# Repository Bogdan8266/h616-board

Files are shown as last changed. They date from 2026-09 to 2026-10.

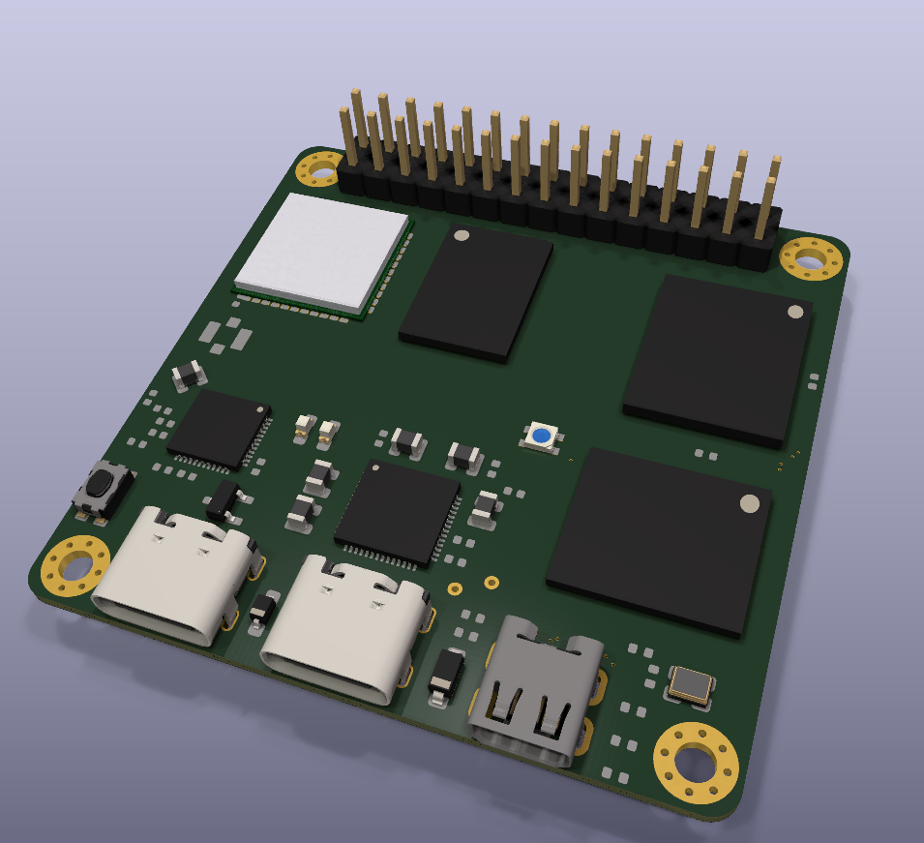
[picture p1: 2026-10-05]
pics/3d-render.png

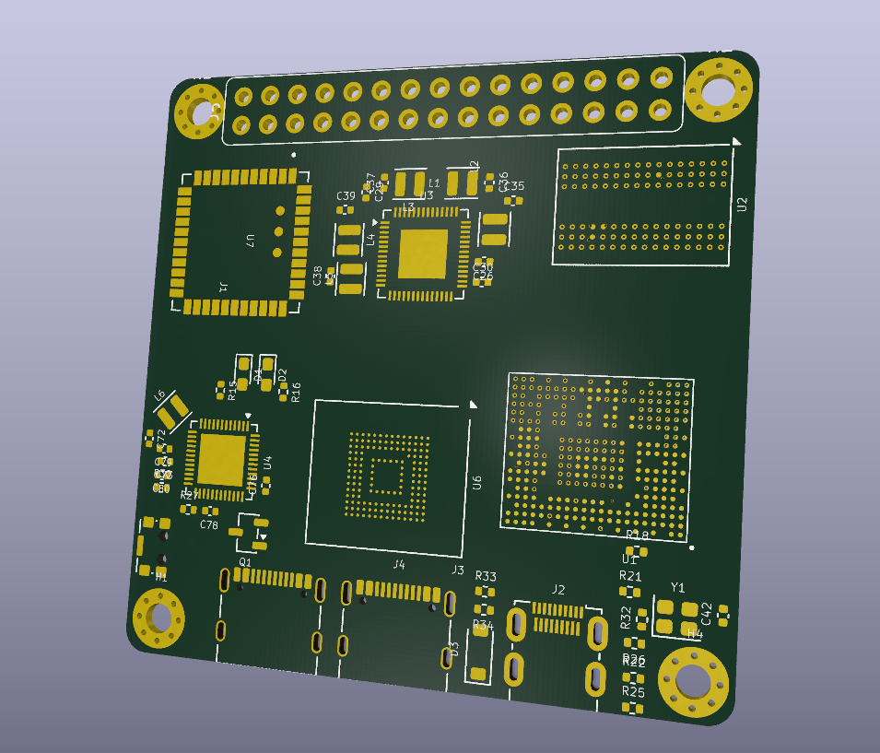
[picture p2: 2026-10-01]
pics/Pasted image (2).png

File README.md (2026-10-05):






# Nebula board

A brief description of my Allwinner H616 board.
A minimalist board measuring 50 mm by 35 mm (subject to change)
# JLCPCB & LCSC
The main challenge with this 8-layer board is using an available stackup from JLCPCB as of August 29, 2026, I recommend [**JLC08101H-1080 (/Finished thickness 1.02 mm ±10%**.](https://jlcpcb.com/pcb-impedance-calculator)
  
Another challenge is that the via holes are 0.3 mm in size (0.35/0.45 mm). 
With these parameters, [JLCPCB](https://cart.jlcpcb.com/) allows you to manufacture the board for $2 USD. Any change will make the price astronomical.
For example, it is not recommended to change the **minimum via hole size/diameter.**
For via covering, I used “via in pad,” so the manufacturer does not allow the via to remain unfilled with epoxy. 
Dimensions up to 50 mm by 40 mm 
If you have the budget, I recommend simply assembling a board based on the original  [Kononenko-K](https://github.com/Kononenko-K/Allwinner_H616_Devboard) design or redesigning my board, because there’s no point in doing this if you don’t want to order a PCB at a promotional price like I did—you’ll waste a lot of energy and may sacrifice stability.

PCB assembly, LCSC isn’t supported in Ukraine, of course, you can use a mail forwarding service, but I’m interested in soldering the board myself and buying parts cheaper on marketplaces—and that same **V3S** costs me practically nothing on the market. If you’re making a board for PCB assembly, it’s worth making it single-sided to save money, but the economical PCBA mode isn’t supported for BGA soldering, and it costs $25, so there’s no point in doing that.
# RAM
My board has only one DDR3 chip, up to 1 GB, but if you’re looking for performance, two chips provide twice as much memory and twice the speed.

It's important to note that the H616 supports 16- or 32-bit RAM; according to **JEDEC**, a single DDR3 chip has a maximum of ***16 bits, so you'll need 16-bit RAM specifically.***

### SK Hynix  
* H5TQ1G63BFR (1 Gb / 128 MB)  
* H5TQ2G63BFR / H5TQ2G63DFR (2 Gb / 256 MB)  
* H5TQ4G63AFR / H5TQ4G63CFR / H5TQ4G63MFR (4 Gb / 512 MB)  
* H5TC8G63AMR / H5TC8G63CMR (8 Gb / 1 GB — low-voltage DDR3L)  
### Samsung  
* K4B1G1646G / K4B1G1646I (1 Gb / 128 MB)  
* K4B2G1646E / K4B2G1646F (2 Gb / 256 MB)  
* K4B4G1646D / K4B4G1646E (4 Gb / 512 MB)  
* K4B8G1646D / K4B8G1646B (8 Gb / 1 GB)  
### Micron  
* MT41J64M16 (1 Gb / 128 MB)  
* MT41J128M16 / MT41K128M16 (2 Gb / 256 MB)  
* MT41J256M16 / MT41K256M16 (4 Gb / 512 MB)  
* MT41J512M16 / MT41K512M16 (8 Gb / 1 GB)  
### Nanya  
* NT5CB64M16 (1 Gb / 128 MB)  
* NT5CB128M16 / NT5CC128M16 (2 Gb / 256 MB)  
* NT5CB256M16 / NT5CC256M16 (4 Gb / 512 MB)  
* NT5CC512M16 (8 Gb / 1 GB)**

## EDA
I’m screwing around with the layout because the DDR was really hard to route, and I lost all motivation working in KiCad—the wise will skip KiCad and download Altium, so think carefully about which software to use. 
## Connection
For Wi-Fi/Bluetooth, I’d choose a board based on the **RTL8821CS** for better speed and so on, because Wi-Fi connects via GPIO (i.e., **SDIO**) and Bluetooth via **UART**. But since there are 3 free USB channels, I’ll connect an **RTL8821CU** board to them for a simple USB connection. Feel free to use any other wireless module that suits your needs; **5 (5.8) GHz** support is important to me, which is why I chose the RTL8821CU, but I recommend taking a closer look at Broadcom options.

## Power

Since I’m planning for standalone operation, and the PMIC **AXP305** wasn’t designed for that—only for monotonous operation from a power supply in TV set-top boxes—it doesn’t support a battery, and there’s certainly no datasheet for it. According to the developer, we’re supposed to use only the reference design together with the **H616**—so be it. 

The **SW6206** is a versatile “all-in-one” microcontroller for power banks that supports fast charging up to 22.5 W. It supports simultaneous operation of up to 5 ports and is compatible with nearly all modern power delivery protocols, including ***PD 3.0, QC 4+, and PPS.***
Therefore, if you plan to run the device on battery power, one USB port is dedicated exclusively to charging; it is not used for data transmission with the board, since smart charging protocols like QC and PD require a data line in the cable.
 # Flux & Paste

For *double-sided soldering*, I recommend purchasing solder pastes: low-temperature (bismuth-based, **~138°C)** and medium-/high-temperature (lead-based, **~183°C**, or lead-free, **~217°C**).

**MECHANIC V5B45** Sn42/Bi58 Solder Paste: Composition and Temperature: Tin-bismuth alloy (Sn42/Bi58) with a precise melting point of **138°C**. For the top side of **BGAs**.

**BS458** Mechanic Solder Paste: Features: A low-melting-point, lead-free, RoHS-compliant formulation supplied in convenient jars. For the back side, resistors, and capacitors.

# Documentation & Soldering      WARNING!!!
[***This***](https://csbible.com/wp-content/uploads/2018/03/CSB_Pew_Bible_2nd_Printing.pdf)
<p align="right"> 
  Views
</p>

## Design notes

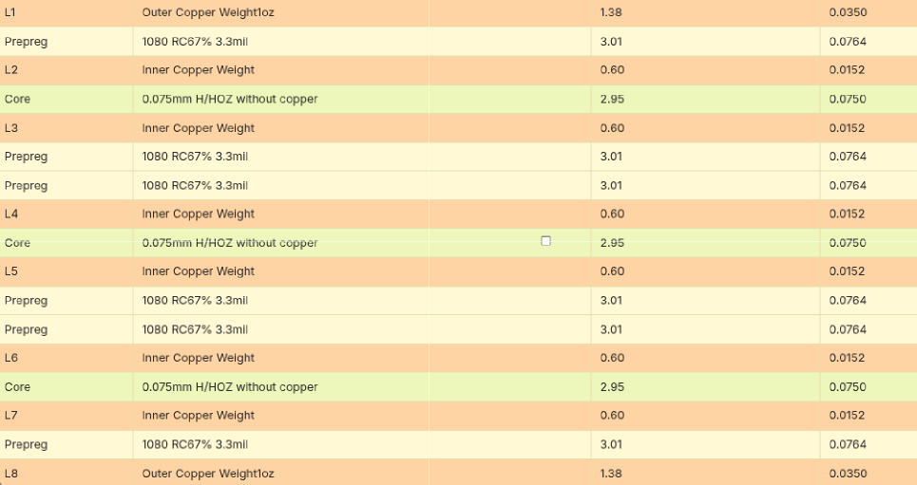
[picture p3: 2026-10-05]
pics/stack2.png

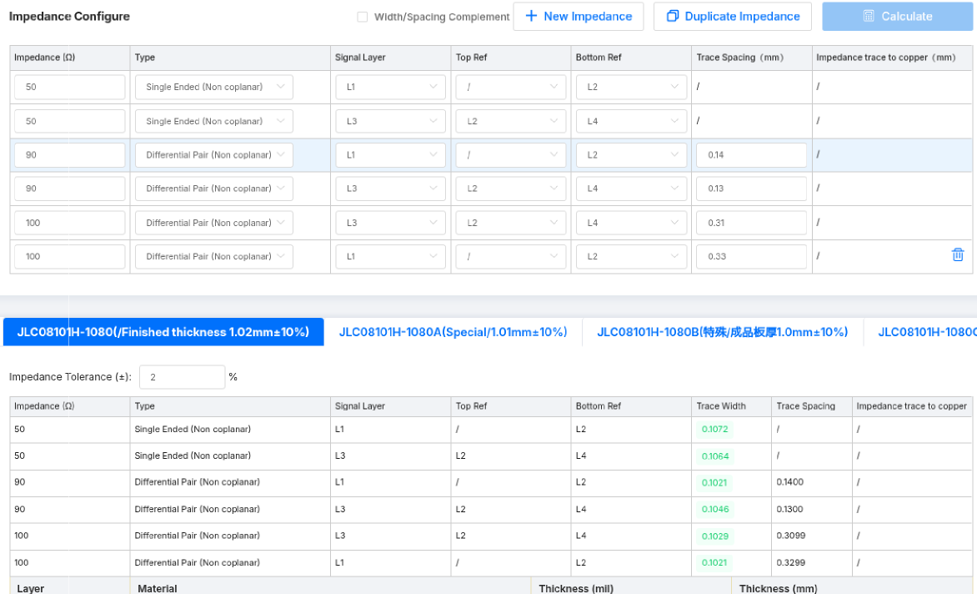
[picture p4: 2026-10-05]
pics/stack.png

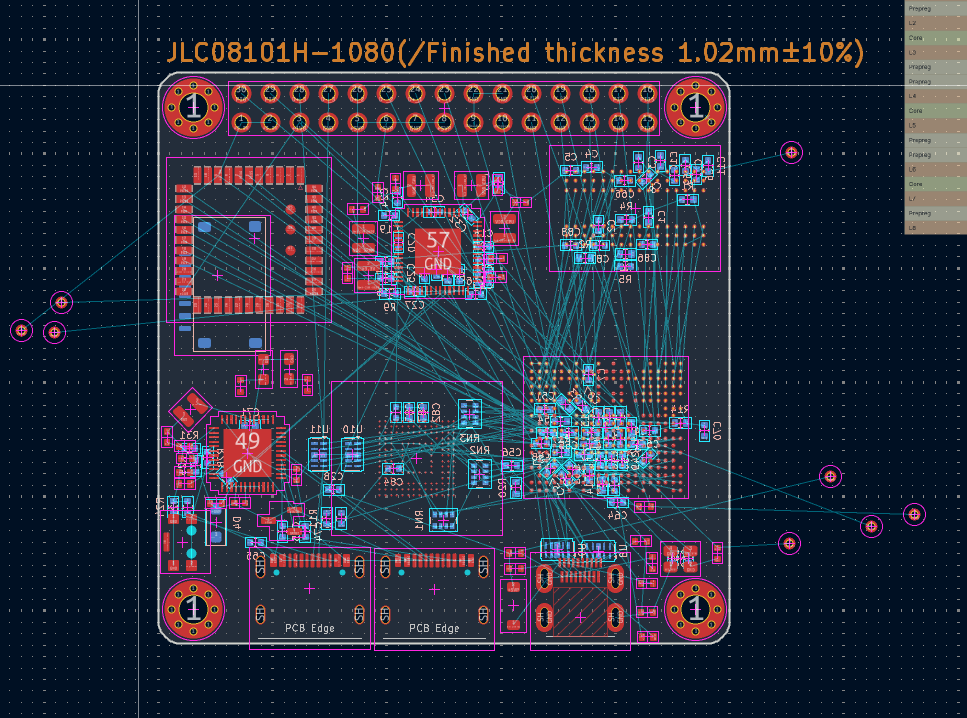
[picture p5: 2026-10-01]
pics/Pasted image.png

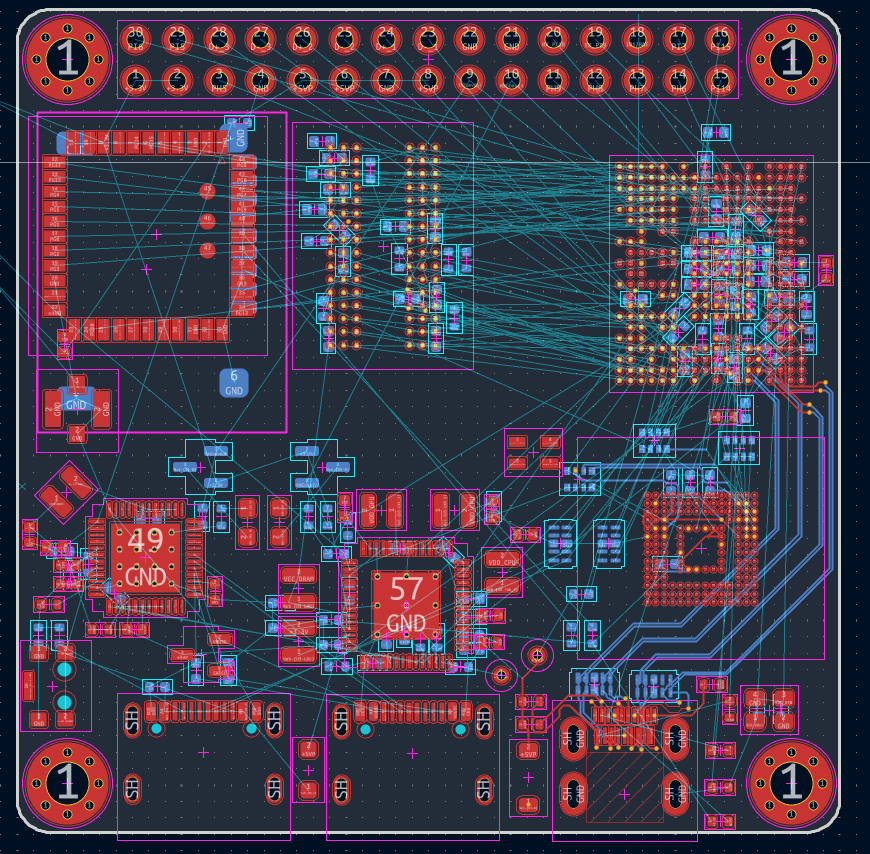
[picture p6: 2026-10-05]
pics/pcb.png

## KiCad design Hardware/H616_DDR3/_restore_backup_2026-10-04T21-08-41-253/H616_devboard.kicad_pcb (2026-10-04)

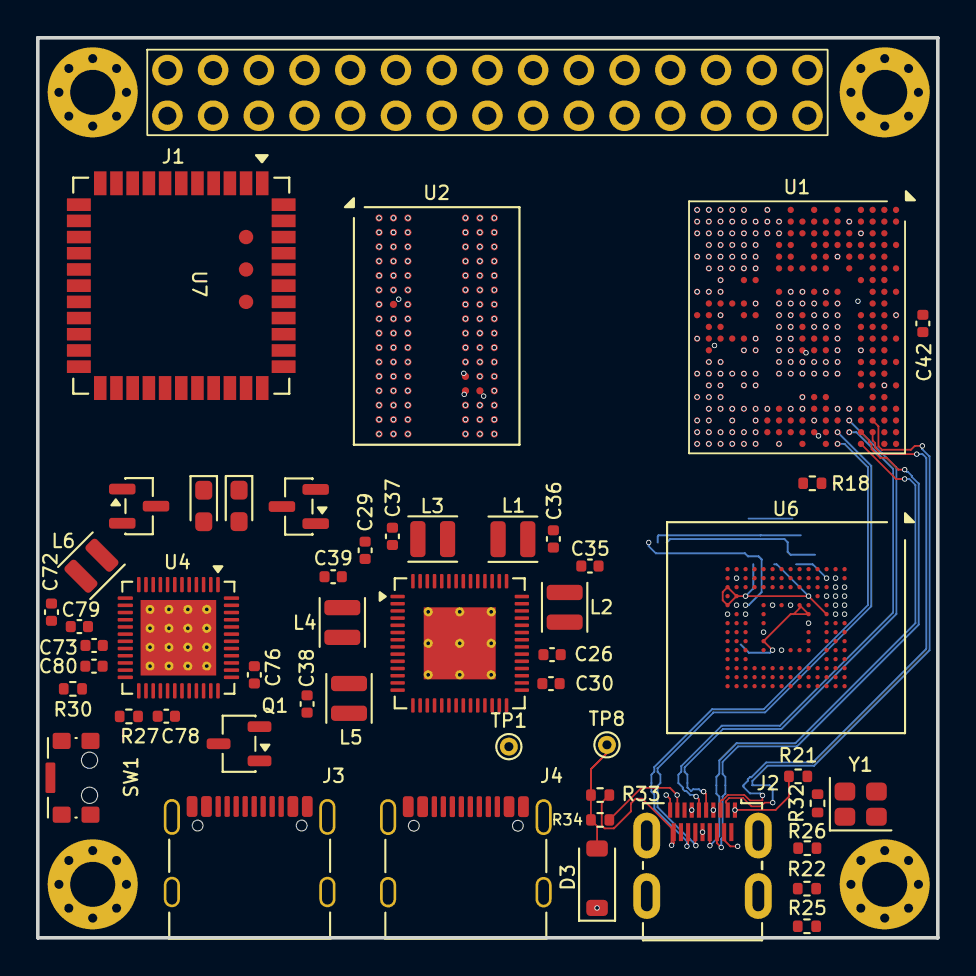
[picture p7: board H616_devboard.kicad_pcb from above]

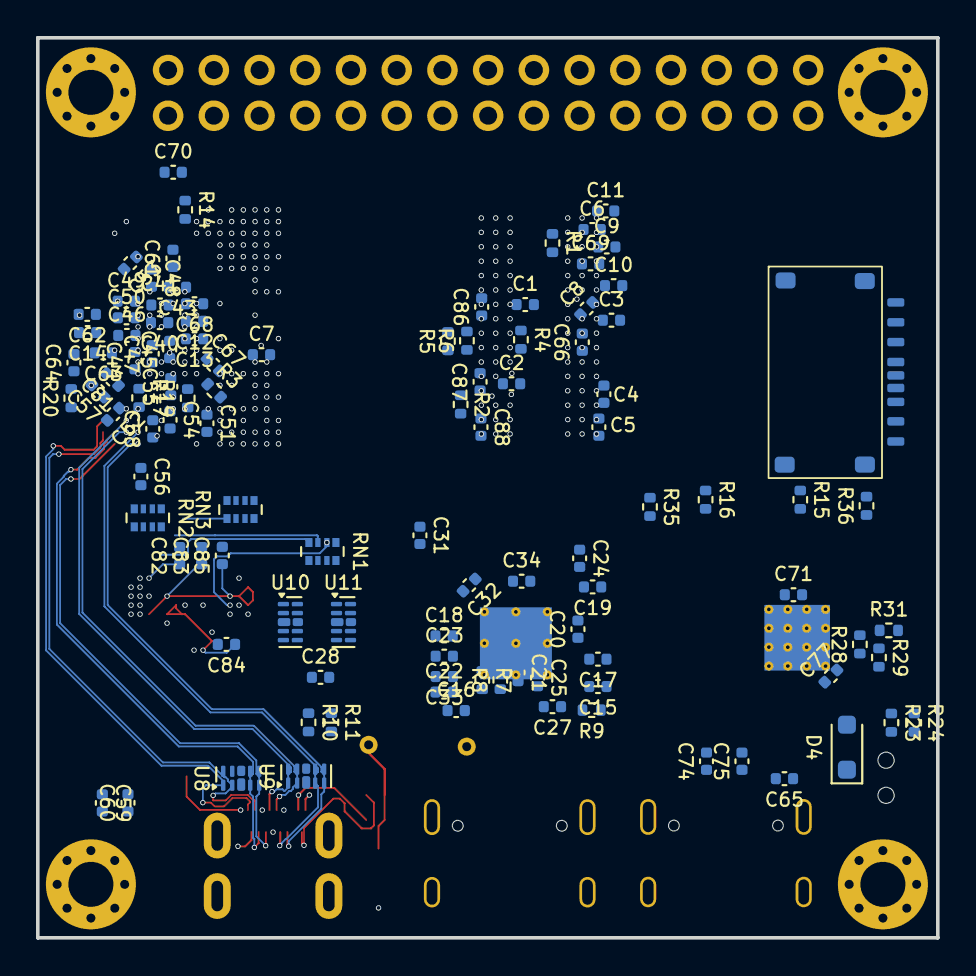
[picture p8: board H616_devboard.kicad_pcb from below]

Board: 8 copper layers, 50.0 x 50.0 mm, 161 parts (105 on the bottom side), 183 nets.

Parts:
C1, C2, C58, C61, C62, C70, C71: 100n; C_0402_1005Metric
C3, C4, C5, C6, C8, C9, C10, C11, C12, C13, C14, C22, C57, C66, C67, C68, C69, C82, C86, C87, C88: 1u; C_0402_1005Metric
C7: 2.2p; C_0402_1005Metric
C15, C16, C17, C18, C19, C20, C23, C24, C25, C26, C27, C28, C29, C30, C31, C32, C33, C34, C35, C36, C37, C38, C39, C51: 10u; C_0402_1005Metric
C21, C65: 4.7u; C_0402_1005Metric
C40, C41, C42, C43, C44, C45, C46, C47, C48, C49, C50, C52, C53, C56, C81, C84: 2.2u; C_0402_1005Metric
C54, C55: 470n; C_0402_1005Metric
C59, C60: 18p; C_0402_1005Metric
C63: 220n; C_0402_1005Metric
C64: 1n; C_0402_1005Metric
C72, C73, C77, C79, C80: 22uF; C_0402_1005Metric
C74, C75, C76: 330pF; C_0402_1005Metric
C78: 100nF; C_0402_1005Metric
C83, C85: 0.1u; C_0402_1005Metric
D1, D2: LED; LED_0603_1608Metric_Pad1.05x0.95mm_HandSolder
D3: B5819W; D_SOD-123
D4: D_Schottky; D_SOD-323_HandSoldering
H1, H1#2, H2, H4: MountingHole; MountingHole_2.5mm_Pad_Via
J1: Micro_SD_Card_Det2; sd-short
J2: HDMI_D_1.4; HDMI_Micro-D_Molex_46765-1xxx
J3, J4: USB_C_Receptacle_USB2.0; USB_C_Receptacle_Palconn_UTC16-G
J5: Conn_01x40_Pin; DIP-30_100
L1, L2, L3, L4, L5: 1,5uH; L_Changjiang_FNR252010S
L6: 2.2uH; L_Changjiang_FNR252010S
Q1: AO3420_C358680; SOT-23-3
Q2, Q3: AO3401A; SOT-23
R1, R2, R15, R16, R17, R18: 2k; R_0402_1005Metric
R3, R5, R6: 240R; R_0402_1005Metric
R4: 100R; R_0402_1005Metric
R7, R9: 0R; R_0402_1005Metric
R8: NC; R_0402_1005Metric
R10: 1R; R_0402_1005Metric
R11: 33R; R_0402_1005Metric
R14: 1k; R_0402_1005Metric
R19: 150k; R_0402_1005Metric
R20, R35, R36: 10k; R_0402_1005Metric
R21: 1K; R_0402_1005Metric
R22: 2K; R_0402_1005Metric
R23, R24: 5.1k; R_0402_1005Metric
R25: 27K; R_0402_1005Metric
R26, R32: 100; R_0402_1005Metric
R27: 5mR; R_0402_1005Metric
R28, R29, R31: 10K; R_0402_1005Metric
R30: 20K; R_0402_1005Metric
R33, R34: 1.8K; R_0402_1005Metric
RN1, RN2, RN3: R_Pack04; R_Array_Convex_4x0402
SW1: CK_KMS2xxG; SW_SPST_CK_KMS2xxGP
TP1, TP8: TestPoint; TestPoint_THTPad_D1.0mm_Drill0.5mm
U1: H616; H616_TFBGA284
U2: K4B8G1646D; BGA-96_9.0x13.0mm_Layout2x3x16_P0.8mm
U3: AXP305; QFN-56-1EP_7x7mm_P0.4mm_EP4x4mm_ThermalVias
U4: SW6206; QFN-48-1EP_6x6mm_P0.4mm_EP4.2x4.2mm_ThermalVias
U6: KLMBG2JETD-B041; LFBGA-153_11.5x13mm_Layout14x14_P0.5mm
U7: AP6256; AP6255
U8, U9, U10, U11: D3V3XA4B10LP; Diodes_UDFN-10_1x2.5mm_P0.5mm
Y1: 24MHz; Crystal_SMD_2520-4Pin_2.5x2.0mm

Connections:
3V3_EXT: C18.2, C23.2, U3.31 (ALDO2), U3.32 (ALDO3)
+1V8: C14.1, C19.2, C53.1, C58.1, C83.1, C85.1, J5.3, R17.2, R18.2, RN1.5 (R4.2), RN1.6 (R3.2), RN1.7 (R2.2), RN1.8 (R1.2), RN2.5 (R4.2), RN2.6 (R3.2), RN2.7 (R2.2), RN2.8 (R1.2), RN3.7 (R2.2), RN3.8 (R1.2), U1.D7 (VCC_PG), U1.D11 (VCC_DCXO), U1.D12 (VCC_PLL), U1.F5 (VCC_PC), U1.F18 (VCC_HDMI), U1.H17 (AVCC), U1.H20 (VCC_TV), U1.L14 (VDD18_DRAM), U3.2 (BLDO1), U6.C6 (VDD), U6.M4 (VDD), U6.N4 (VDD), U6.P3 (VDD), U6.P5 (VDD), U7.22 (VDDIO)
+3.3V: C38.2, C51.1, C52.1, C61.1, C62.1, C84.1, J5.1, J5.2, L5.2, Q2.2 (S), Q3.2 (S), R10.2, R20.1, R25.1, R35.1, R36.1, RN3.5 (R4.2), RN3.6 (R3.2), U1.D10 (VCC_IO), U1.E18 (VCC_EPHY), U1.J6 (VCC_PI), U1.M18 (VCC_USB), U3.10 (DCDCE), U6.E6 (VDDF), U6.F5 (VDDF), U6.J10 (VDDF), U6.K9 (VDDF), U7.9 (VBAT)
+5VP: C15.2, C17.2, C20.2, C26.2, C27.2, C28.2, C29.1, C30.1, C31.1, C32.1, C33.1, C34.2, C78.2, C79.1, D3.2 (A), D4.2 (A_2), J5.5, J5.6, J5.8, Q1.3 (D), R27.1, R33.1, R34.2, TP8.1 (1_1), U3.3 (BLDOIN), U3.6 (VIND), U3.13 (VINE), U3.18 (CLDOIN), U3.30 (ALDOIN), U3.33 (VINB_1), U3.34 (VINB_2), U3.45 (VINA_2), U3.46 (VINA_1), U3.52 (VINC_2), U3.53 (VINC_1), U4.13 (VOUTC), U4.28 (VOUTSN)
/CHARGE/BAT: C72.1, C73.1, L6.1, U4.17 (BAT)
/CHARGE/CC1: C75.1, J4.A5 (CC1), U4.40 (CC2)
/CHARGE/CC2: C74.1, J4.B5 (CC2), U4.41 (CC1)
/CHARGE/DMC: J4.A7 (D-), J4.B7 (D-), U4.42 (DMC)
/CHARGE/DPC: J4.A6 (D+), J4.B6 (D+), U4.43 (DPC)
/CHARGE/GATEC: Q1.1 (G), U4.38 (GATEC)
/CHARGE/VBUSC: J4.A4 (VBUS), J4.A9 (VBUS), J4.B4 (VBUS), J4.B9 (VBUS), Q1.2 (S), U4.12 (VBUSC)
/CHARGE/VCC: C80.1, R28.2, R29.1, U4.19 (VCC)
/CHARGE/VOUTSP: C77.1, C78.1, R27.2, U4.27 (VOUTSP), U4.29 (VOUT), U4.30 (VOUT), U4.31 (VOUT), U4.32 (VOUT), U4.33 (VOUT)
/DRAM/DQ0: U1.V3 (SDQ9), U2.E3 (DQ0)
/DRAM/DQ1: U1.P6 (SDQ14), U2.F7 (DQ1)
/DRAM/DQ2: U1.R4 (SDQ11), U2.F2 (DQ2)
/DRAM/DQ3: U1.R6 (SDQ12), U2.F8 (DQ3)
/DRAM/DQ4: U1.N4 (SDQ13), U2.H3 (DQ4)
/DRAM/DQ5: U1.P5 (SDQ8), U2.H8 (DQ5)
/DRAM/DQ6: U1.P4 (SDQ10), U2.G2 (DQ6)
/DRAM/DQ7: U1.N5 (SDQ15), U2.H7 (DQ7)
/DRAM/DQ8: U1.T4 (SDQ3), U2.D7 (DQ8)
/DRAM/DQ9: U1.P1 (SDQ5), U2.C3 (DQ9)
/DRAM/DQ10: U1.U4 (SDQ1), U2.C8 (DQ10)
/DRAM/DQ11: U1.P2 (SDQ7), U2.C2 (DQ11)
/DRAM/DQ12: U1.T2 (SDQ6), U2.A7 (DQ12)
/DRAM/DQ13: U1.N3 (SDQ0), U2.A2 (DQ13)
/DRAM/DQ14: U1.U3 (SDQ4), U2.B8 (DQ14)
/DRAM/DQ15: U1.N2 (SDQ2), U2.A3 (DQ15)
/DRAM/SA0: U1.P18 (SACT), U2.N3 (A0)
/DRAM/SA1: U1.R15 (SBA1), U2.P7 (A1)
/DRAM/SA2: U1.T18 (SA2), U2.P3 (A2)
/DRAM/SA3: U1.R19 (SA10), U2.N2 (A3)
/DRAM/SA4: U1.U16 (SA12), U2.P8 (A4)
/DRAM/SA5: U1.R20 (SCS1), U2.P2 (A5)
/DRAM/SA6: U1.N13 (SA15), U2.R8 (A6)
/DRAM/SA7: U1.T21 (SA0), U2.R2 (A7)
/DRAM/SA8: U1.V17 (SCS0), U2.T8 (A8)
/DRAM/SA9: U1.T20 (SODT0), U2.R3 (A9)
/DRAM/SA10: U1.U19 (SA8), U2.L7 (A10/AP)
/DRAM/SA11: U1.U17 (SA1), U2.R7 (A11)
/DRAM/SA12: U1.P16 (SA13), U2.N7 (A12/~BC)
/DRAM/SA13: U1.R18 (SA4), U2.T3 (A13)
/DRAM/SA14: U1.P15 (SA5), U2.T7 (A14)
/DRAM/SA15: U1.U18 (SA16), U2.M7 (A15)
/DRAM/SBA0: U1.P20 (SBG0), U2.M2 (BA0)
/DRAM/SBA1: U1.U15 (SA11), U2.N8 (BA1)
/DRAM/SBA2: U1.U20 (SA6), U2.M3 (BA2)
/DRAM/SCAS: U1.N16 (SA9), U2.K3 (~CAS)
/DRAM/SCKE0: U1.V15 (SCKE0), U2.K9 (CKE)
/DRAM/SCKE1: U1.P13 (SCKE1), U2.J9 (CKE1)
/DRAM/SCKN: C7.2, R4.2, U1.U14 (SCKN), U2.K7 (~CK)
/DRAM/SCKP: C7.1, R4.1, U1.T14 (SCKP), U2.J7 (CK)
/DRAM/SCS0: U1.P21 (SBG1), U2.L2 (~CS)
/DRAM/SCS1: U1.N19 (SA7), U2.L1 (CS1#)
/DRAM/SDQM0: U1.U1 (SDQM0), U2.D3 (UDM)
/DRAM/SDQM1: U1.R3 (SDQM1), U2.E7 (LDM)
/DRAM/SDQS0N: U1.R1 (SDQS0N), U2.B7 (~UDQS)
/DRAM/SDQS0P: U1.R2 (SDQS0P), U2.C7 (UDQS)
/DRAM/SDQS1N: U1.V2 (SDQS1N), U2.G3 (~LDQS)
/DRAM/SDQS1P: U1.U2 (SDQS1P), U2.F3 (LDQS)
/DRAM/SODT0: U1.N20 (SODT1), U2.K1 (ODT)
/DRAM/SODT1: U1.N21 (SBA0), U2.J1 (ODT1)
/DRAM/SRAS: U1.T16 (SA3), U2.J3 (~RAS)
/DRAM/SRST: U1.U21 (SRST), U2.T2 (~RESET)
/DRAM/SVREF: C1.2, C2.1, C3.1, R1.2, R2.1, U2.H1 (VREFDQ), U2.M8 (VREFCA)
/DRAM/SWE: U1.V20 (SA14), U2.L3 (~WE)
/IO1/DAT0: RN1.3 (R3.1), U1.E3 (PC8), U6.A3 (DAT0)
/IO1/DAT1: RN1.4 (R4.1), U1.F1 (PC9), U6.A4 (DAT1)
/IO1/DAT2: RN3.1 (R1.1), U1.F2 (PC10), U6.A5 (DAT2)
/IO1/DAT3: RN3.2 (R2.1), U1.F3 (PC11), U6.B2 (DAT3)
/IO1/DAT4: RN2.1 (R1.1), U1.G3 (PC13), U6.B3 (DAT4)
/IO1/DAT5: RN2.2 (R2.1), U1.H1 (PC14), U6.B4 (DAT5)
/IO1/DAT6: RN2.3 (R3.1), U1.H2 (PC15), U6.B5 (DAT6)
/IO1/DAT7: RN2.4 (R4.1), U1.H3 (PC16), U6.B6 (DAT7)
/IO1/DATA-STROBE: U1.B1 (PC0), U6.H5 (DATA-STROBE)
/IO1/EMMC_CLK: U1.D3 (PC5), U6.M6 (CLK)
/IO1/EMMC_CMD: RN1.2 (R2.1), U1.E2 (PC6), U6.M5 (CDM)
/IO1/EMMC_RSTN: RN1.1 (R1.1), U1.C2 (PC1), U6.K5 (RSTN)
/IO1/PG0: U1.A6 (PG0), U7.17 (SDIO_DATA_CLK)
/IO1/PG1: U1.C7 (PG1), U7.16 (SDIO_DATA_CMD)
/IO1/PG2: U1.C6 (PG2), U7.18 (SDIO_DATA_0)
/IO1/PG3: U1.B5 (PG3), U7.19 (SDIO_DATA_1)
/IO1/PG4: U1.C5 (PG4), U7.14 (SDIO_DATA_2)
/IO1/PG5: U1.B7 (PG5), U7.15 (SDIO_DATA_3)
/IO1/PG6: U1.A4 (PG6), U7.43 (UART_RXD)
/IO1/PG7: U1.B4 (PG7), U7.42 (UART_TXD)
/IO1/PG8: U1.C4 (PG8), U7.44 (UART_CTS_N)
/IO1/PG9: U1.B3 (PG9), U7.41 (UAR_RTS_N)
/IO1/PG11: U1.B10 (PG11), U7.12 (WL_REG_ON)
/IO1/PG12: U1.C9 (PG12), U7.34 (BT_REG_ON)
/IO1/PG13: U1.C10 (PG13), U7.13 (WL_HOST_WAKE)
/IO1/PG14: U1.B9 (PG14), U7.7 (BT_HOST_WAKE)
/IO1/PG15: U1.A8 (PG15), U7.6 (BT_WAKE)
/IO1/PH6: J5.14, U1.C14 (PH6)
/IO1/PH7: J5.13, U1.B12 (PH7)
/IO1/PH8: J5.12, U1.C13 (PH8)
/IO1/PH9: J5.11, U1.A12 (PH9)
/IO1/PI2: J5.18, U1.G6 (PI2)
/IO1/PI3: J5.17, U1.E4 (PI3)
/IO1/PI5: J5.29, U1.H4 (PI5)
/IO1/PI6: J5.30, U1.H5 (PI6)
/IO1/PI14: J5.15, U1.L6 (PI14)
/IO1/PI15: J5.16, U1.L4 (PI15)
/IO1/RX_PI10: J5.20, U1.L5 (PI10)
/IO1/SDC0_CLK: R11.2, U1.K1 (PF2)
/IO1/SDC0_CMD: RN3.3 (R3.1), U1.K3 (PF3)
/IO1/SDC0_DET: R14.2, RN3.4 (R4.1), U1.K2 (PF6)
/IO1/TX_PI9: J5.19, U1.D5 (PI9)
/IO1/VDDI: C82.1, U6.C2 (VDDI)
/IO2/CK+: J2.12 (CK+), U1.F20 (HTXCP), U9.4
/IO2/CK-: J2.14 (CK-), U1.F21 (HTXCN), U9.5
/IO2/D0+: J2.9 (D0+), U1.E19 (HTX0P), U9.1
/IO2/D0-: J2.11 (D0-), U1.E20 (HTX0N), U9.2
/IO2/D1+: J2.6 (D1+), U1.D20 (HTX1P), U8.4
/IO2/D1-: J2.8 (D1-), U1.D21 (HTX1N), U8.5
/IO2/D2+: J2.3 (D2+), U1.C19 (HTX2P), U8.1
/IO2/D2-: J2.5 (D2-), U1.C20 (HTX2N), U8.2
/IO2/HCEC: J2.15 (CEC), R25.2, U1.G17 (HCEC)
/IO2/HHPD: R21.2, R22.1, U1.G18 (HHPD)
/IO2/HSCL: R26.2, U1.F19 (HSCL)
/IO2/HSDA: R32.1, U1.G21 (HSDA)
/IO2/SOC_XIN: C59.2, U1.B11 (DXIN), Y1.3
/IO2/SOC_XOUT: C60.2, U1.C12 (DXOUT), Y1.1
/POWER/ALDO1: C16.2, U3.28 (ALDO1)
/POWER/VDD_CPU: C35.1, C36.1, C41.2, C43.2, C45.2, C47.2, L1.2, L2.2, U1.H8 (VDD_CPU1), U1.H9 (VDD_CPU2), U1.J8 (VDD_CPU3), U1.J9 (VDD_CPU4), U1.J10 (VDD_CPU5), U1.J11 (VDD_CPU6)
/POWER/VDD_CPUFB: U1.L8 (VDD_CPUFB), U3.39 (DCDCB), U3.40 (DCDCA)
/POWER/VDD_GPU: C37.1, C40.2, C42.2, C44.2, C46.2, C48.2, C49.2, C50.2, C81.2, L3.2, U1.F9 (VDD_GPU1), U1.F10 (VDD_GPU2), U1.F11 (VDD_SYS1), U1.F12 (VDD_SYS2), U1.F13 (VDD_SYS3), U1.G8 (VDD_GPU3), U1.G9 (VDD_GPU4), U1.G10 (VDD_SYS4), U1.G11 (VDD_SYS5), U1.G12 (VDD_SYS6)
/POWER/VDD_GPUFB: U1.F8 (VDD_GPUFB), U3.47 (DCDCC)
/POWER/VINT: C21.2, R8.1, U3.25 (VINT)
AP_RESET: C64.1, R9.1, R20.2, U1.A16 (RESET)
D+: J3.A6 (D+), J3.B6 (D+), U1.J20 (USB0_DP), U11.4
D+_1: J5.24, U1.M20 (USB1_DP), U10.1
D+_2: J5.26, U1.K20 (USB2_DP), U10.4
D+_3: J5.28, U1.L20 (USB3_DP), U11.1
D-: J3.A7 (D-), J3.B7 (D-), U1.J19 (USB0_DM), U11.5
D-_1: J5.23, U1.M19 (USB1_DM), U10.2
D-_2: J5.25, U1.K19 (USB2_DM), U10.5
D-_3: J5.27, U1.L19 (USB3_DM), U11.2
GND: C2.2, C3.2, C4.2, C5.2, C6.2, C8.2, C9.2, C10.2, C11.2, C12.2, C13.2, C14.2, C15.1, C16.1, C17.1, C18.1, C19.1, C20.1, C21.1, C22.1, C23.1, C24.1, C25.1, C26.1, C27.1, C28.1, C29.2, C30.2, C31.2, C32.2, C33.2, C34.1, C35.2, C36.2, C37.2, C38.1, C39.2, C40.1, C41.1, C42.1, C43.1, C44.1, C45.1, C46.1, C47.1, C48.1, C49.1, C50.1, C51.2, C52.2, C53.2, C54.2, C55.2, C56.2, C57.2, C58.2, C59.1, C60.1, C61.2, C62.2, C63.2, C64.2, C65.1, C66.2, C67.2, C68.2, C69.2, C70.2, C72.2, C73.2, C74.2, C75.2, C76.1, C77.2, C79.2, C80.2, C81.1, C82.2, C83.2, C84.2, C85.2, C86.2, C87.2, C88.2, J2.4 (D2S), J2.7 (D1S), J2.10 (D0S), J2.13 (CKS), J2.16 (GND), J2.SH, J3.A1 (GND), J3.A12 (GND), J3.B1 (GND), J3.B12 (GND), J4.A1 (GND), J4.A12 (GND), J4.B1 (GND), J4.B12 (GND), J5.4, J5.7, J5.21, J5.22, R2.2, R3.2, R5.2, R6.2, R7.1, R14.1, R15.2, R16.2, R19.2, R22.2, R23.1, R24.1, R30.1, R31.2, SW1.1, U1.A1 (GND1), U1.A10 (GND2), U1.A18 (GND3), U1.A21 (GND4), U1.B6 (GND5), U1.B16 (GND6), U1.D19 (GND7), U1.F14 (GND8), U1.F15 (GND9), U1.G13 (GND10), U1.G14 (GND11), U1.G15 (GND12), U1.H10 (GND13), U1.H11 (GND14), U1.H12 (GND15), U1.H13 (GND16), U1.H14 (GND17), U1.H15 (GND18), U1.H18 (AGND), U1.H19 (GND19), U1.J12 (GND20), U1.J13 (GND21), U1.J14 (GND22), U1.J15 (GND23), U1.K8 (GND25), U1.K9 (GND26), U1.K10 (GND27), U1.K11 (GND28), U1.K12 (GND29), U1.K13 (GND30), U1.K14 (GND31), U1.K15 (GND32), U1.L21 (GND33), U1.M1 (GND24), U1.M2 (GND34), U1.M3 (GND35), U1.N6 (GND36), U1.N9 (GND37), U1.N12 (GND38), U1.N15 (GND39), U1.N18 (GND40), U1.P3 (GND41), U1.R5 (GND42), U1.R21 (GND43), U1.T1 (GND44), U1.T3 (GND45), U1.T8 (GND46), U1.T10 (GND47), U1.T15 (GND48), U1.T17 (GND49), U1.U6 (GND50), U1.U13 (GND51), U1.V1 (GND52), U1.V5 (GND53), U1.V12 (GND54), U1.V19 (GND55), U1.V21 (GND56), U2.A9 (VSS), U2.B1 (VSSQ), U2.B3 (VSS), U2.B9 (VSSQ), U2.D1 (VSSQ), U2.D8 (VSSQ), U2.E1 (VSS), U2.E2 (VSSQ), U2.E8 (VSSQ), U2.F9 (VSSQ), U2.G1 (VSSQ), U2.G8 (VSS), U2.G9 (VSSQ), U2.J2 (VSS), U2.J8 (VSS), U2.M1 (VSS), U2.M9 (VSS), U2.P1 (VSS), U2.P9 (VSS), U2.T1 (VSS), U2.T9 (VSS), U3.8 (PGNDD), U3.11 (PGNDE), U3.37 (PGNDB_1), U3.38 (PGNDB_2), U3.41 (PGNDA_2), U3.42 (PGNDA_1), U3.48 (PGNDC_2), U3.49 (PGNDC_1), U3.54 (FBGND), U3.55 (MODESET), U3.57 (GND), U4.23 (LED4/I2C), U4.49 (EPAD), U6.A6 (VSS), U6.C4 (VSS), U6.E7 (VSS), U6.G5 (VSS), U6.H10 (VSS), U6.J5 (VSS), U6.K8 (VSS), U6.N2 (VSS), U6.N5 (VSS), U6.P4 (VSS), U6.P6 (VSS), U8.3 (VSS), U8.8 (VSS), U9.3 (VSS), U9.8 (VSS), U10.3 (VSS), U10.8 (VSS), U11.3 (VSS), U11.8 (VSS), Y1.2, Y1.4
unnamed: C65.2, J3.A4 (VBUS), J3.A9 (VBUS), J3.B4 (VBUS), J3.B9 (VBUS)
unnamed: C71.1, L6.2, U4.2 (SW), U4.3 (SW), U4.4 (SW), U4.5 (SW), U4.6 (SW)
unnamed: D1.2 (A), Q2.3 (D)
unnamed: D1.1 (K), R15.1
unnamed: D2.2 (A), Q3.3 (D)
unnamed: D2.1 (K), R16.1
unnamed: D3.1 (K), J2.19 (+5V)
unnamed: J2.1 (HPD/HEAC-), R21.1
unnamed: J2.17 (SCL), R26.1, R34.1
unnamed: J2.18 (SDA), R32.2, R33.2
unnamed: J3.A5 (CC1), R23.2
unnamed: J3.B5 (CC2), R24.2
unnamed: R3.1, U1.L15 (SZQ)
unnamed: C56.1, U1.D18 (AC_AVCC)
unnamed: C57.1, U1.C17 (AC_VRA1)
unnamed: C63.1, U1.D13 (DXLDO_OUT)
unnamed: R19.1, U1.K18 (REXT)
unnamed: C54.1, U1.J18 (VRA1)
unnamed: C55.1, U1.J17 (VRA2)
unnamed: R5.1, U2.L9 (ZQ1)
unnamed: R6.1, U2.L8 (ZQ)
unnamed: C24.2, U3.1 (BLDO2)
unnamed: C25.2, U3.19 (CLDO1)
unnamed: TP1.1 (1_1), U3.27 (EN/PWRON)
unnamed: L1.1, U3.43 (LXA_2), U3.44 (LXA_1)
unnamed: L2.1, U3.35 (LXB_1), U3.36 (LXB_2)
unnamed: L3.1, U3.50 (LXC_2), U3.51 (LXC_1)
unnamed: L4.1, U3.7 (LXD)
unnamed: L5.1, U3.12 (LXE)
unnamed: R7.2, R8.2, U3.26 (PHSET)
unnamed: R9.2, U3.15 (PWROK)
unnamed: C22.2, U3.29 (VREF)
unnamed: C71.2, U4.7 (BST)
unnamed: C76.2, U4.39 (CCL/WLED)
unnamed: R30.2, U4.22 (CSET)
unnamed: R29.2, U4.21 (FLED/BSET)
unnamed: R28.1, SW1.2, U4.20 (KEY/GSET)
unnamed: R31.1, U4.18 (NTC)
PMU_SCK: R17.1, U1.C18 (PL0), U3.23 (SCK), U4.26 (LED1/SCK)
PMU_SDA: R18.1, U1.B18 (PL1), U3.24 (SDA), U4.25 (LED2/SDA)
RXConvIn: J5.10, Q3.1 (G), R35.2, U1.D16 (PH0)
TXConvOut: J5.9, Q2.1 (G), R36.2, U1.D15 (PH1)
VCC_DRAM: C1.1, C4.1, C5.1, C6.1, C8.1, C9.1, C10.1, C11.1, C12.1, C13.1, C39.1, C66.1, C67.1, C68.1, C69.1, C86.1, C87.1, C88.1, L4.2, R1.1, U1.L9 (VCC_DRAM1), U1.L10 (VCC_DRAM2), U1.L11 (VCC_DRAM3), U1.L12 (VCC_DRAM4), U1.L13 (VCC_DRAM5), U2.A1 (VDDQ), U2.A8 (VDDQ), U2.B2 (VDD), U2.C1 (VDDQ), U2.C9 (VDDQ), U2.D2 (VDDQ), U2.D9 (VDD), U2.E9 (VDDQ), U2.F1 (VDDQ), U2.G7 (VDD), U2.H2 (VDDQ), U2.H9 (VDDQ), U2.K2 (VDD), U2.K8 (VDD), U2.N1 (VDD), U2.N9 (VDD), U2.R1 (VDD), U2.R9 (VDD), U3.9 (DCDCD)

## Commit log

2026-08-28 Rename project to Nebula board and update details
    Updated README to reflect new project name and added details about the Nebula board, including hardware specifications and assembly recommendations.
2026-08-29 Add badges to README for project status and tools
    Added badges for status, KiCad, SoC, BuildRoot, and JLCPCB.
2026-10-01 Fix critical hardware bugs: eMMC HS400, AXP305 power rails, SW6206 Kelvin sense, Type-C CC and hierarchy
    [H616_devboard.kicad_sch, board.kicad_sch, charge.kicad_sch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]
2026-10-06 buttons, pcb
    [H616_devboard.kicad_pcb, charge.kicad_sch]
2026-10-08 ddr3 trace
    [H616_devboard.kicad_pcb]
2026-10-11 Fix formatting of Board Layout & Architecture header
2026-10-13 ddr trace
2026-10-24 ddr trace. rules
2026-10-30 ddr trace final
2026-10-31 usb trace
2026-11-01 emmc trace, sch
2026-11-01 emmc trace
2026-11-02 fanout and emmc trace
2026-11-04 trace board
